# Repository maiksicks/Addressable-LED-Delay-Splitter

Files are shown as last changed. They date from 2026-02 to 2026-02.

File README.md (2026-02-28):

# Addressable LED Delay Splitter (WS2812B / SK6812)

This project implements a "delay splitter" for addressable LED strips (WS2812B / SK6812) using an [ATtiny406](https://www.microchip.com/en-us/product/attiny406) microcontroller.
The device should work for all 800 kHz LED strips that only use one data line.

> Inspired by [WS2812B Delay Splitter](https://hackaday.io/project/8181-ws2812b-delay-splitter) that uses a [CMIC](https://en.wikipedia.org/wiki/Configurable_mixed-signal_IC) for this task.

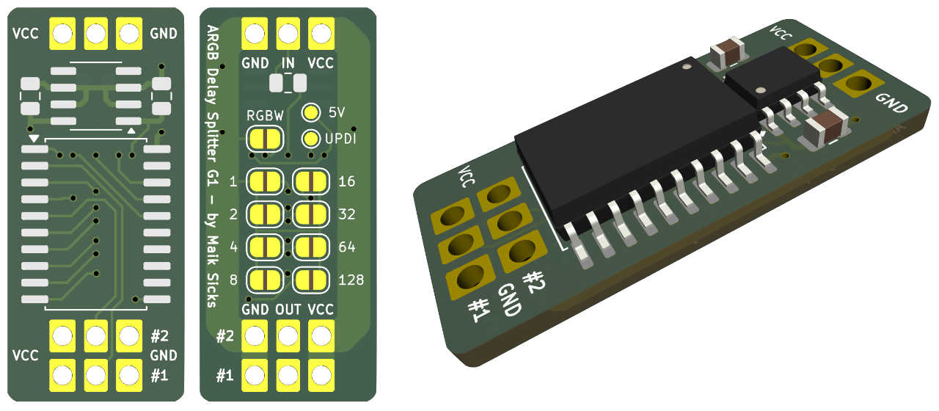
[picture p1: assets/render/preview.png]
Preview of the delay splitter


> [!NOTE]
> More images are available in the [Gallery](./docs/Gallery.md). Including a short demo video showing the device in action.

## Description

The splitter takes a single LED data stream as input and provides two outputs:

- **Primary output**: This channel outputs the first N pixels of the input stream, where N is the configured pixel number.

- **Secondary output**: This channel outputs the remaining pixels of the input stream after the first N pixels.

### Basic use-case

- `pixel delay = 3`
    ```
                                 +- (1) - (2) - (3)
    [Controller] --- [Splitter] -+
                                 +- (4) - (5) - (6)
    ```

- `pixel delay = 3` and `primary passthrough = on`
    ```
                                 +- (1) - (2) - (3) - (4) - (5) - (6)
    [Controller] --- [Splitter] -+
                                 +- (4) - (5) - (6)
    ```

- Chaining
    ```
                                 +- (1) - (2) - (3)
    [Controller] --- [Splitter] -+
                                 +- [Splitter] ...
    ```
    ```
    [Controller] --- (1) - (2) - (3) --- [Splitter] ...
    ```

### How it works

Due to the high frequency of the WS2812B protocol (800kHz, 1.25µs per bit), the splitter uses many hardware features of the ATtiny406 to achieve the required timing:

- **Event System**
  Distribute the different signals (data input and control pin) to the various peripherals w(mostly) without CPU intervention.

- **CCL (Configurable Custom Logic)**
  Look-up tables (LUTs) are used to asynchronously route the input data stream to the outputs.

  - `Output_1 = Input_1 AND NOT Control_Pin`
  - `Output_2 = Input_1 AND Control_Pin`

- **TCA0 (Bit Counter)**
  Counts the number of bits / rising edges / events received via the event system. When the configured number of bits (delay) is reached, the control pin is switched to route the data to output 2.

- **TCB0 (Timeout Timer)**
  When the control pin is switched to output 2, this timer is started. If no rising edges are detected for a certain amount of time (indicating the reset condition of the WS2812B), the control pin is switched back to output 1.

## Configuration

The device can be configured via jumpers or by hardcoding values in `config.hpp`.

### Jumper configuration

There are 8 jumpers available to configure the pixel delay. The delay can be set from 0 to 255 pixels.

There is an additional jumper to change from RGB mode (24 bits per pixel) to RGBW mode (32 bits per pixel).

### Hardcoded configuration

The following parameters can be hardcoded in `config.hpp`:

- `PIXEL_DELAY` - Number of pixels to delay the output
- `RGBW_MODE` - Enable RGBW mode (32 bits per pixel instead of 24)
- `BITS_PER_PIXEL` - Number of bits per pixel (24 for RGB, 32 for RGBW)
- `SWAP_OUTPUTS` - Swap the primary and secondary outputs (output 1 and output 2)
- `PRIMARY_OUTPUT_PASSTHROUGH` - Enable passthrough of the primary output. When enabled, the primary output will not be turned off when the secondary output is active.
- `DISABLE_OUTPUT_1` and `DISABLE_OUTPUT_2` - Self-explanatory :)
- `LED_RESET_TIMEOUT` - Duration (in microseconds) to detect the reset condition of the WS2812B. The default is 50µs, which is a safe value for up to ~800kHz data rates.

Special parameters:

- `FORCE_SHORTED_CONTROL_PIN` - Forces the _shorted configuration pin mode_ to be enabled. This mode will be automatically enabled if jumper "128" is used. The control signal will then be inverted internally instead of setting the pin HIGH and LOW. 
  _Background: This mode had to be introduced because the hardware design of the splitter (revision 1) already had all Port B pins used for the configuration jumpers. The Event System only supports Port B pins as event generators on `ASYNCCH1`._

### Operation voltage

The device contains an onboard voltage regulator that can accept input voltages up to 30V (absolute maximum rating). Therefore, the recommend input voltages are 12V and 24V.

It is also possible to power the device with 5V. However, in this case, the voltage regulator will not be able to provide a stable 5V output for the ATtiny406. It may be a good idea to remove the voltage regulator and connect the 5V pin directly to the VCC pin.

### Flashing

The project can be built and flashed using [PlatformIO](https://platformio.org/).

For flashing, an UPDI programmer is required. 
You can also build a simple UPDI programmer using an Arduino Uno/Nano with ATmega328P:

1. Download the [jtag2updi repository](https://github.com/ElTangas/jtag2updi).
2. Rename the `source` folder to `jtag2updi` (otherwise Arduino IDE will not open it).
3. Open the `jtag2updi.ino` file using the Arduino IDE.
4. Connect the Arduino, select the correct board and port in the Arduino IDE, and upload the sketch.

After this, you can connect pin 6 of the Arduino to the UPDI pin of the ATtiny406, and use PlatformIO to flash the splitter firmware.

## Limitations

There is a maximum amount of leds that can be connected to a single data line. This limit is determined by the data rate of the LEDs. The formula to calculate the maximum number of LEDs is:

`N = ( (1 / f) - T_reset ) / ( B / R )`

Where:
- `N` = maximum number of LEDs
- `f` = frames per second (e.g. 60Hz)
- `T_reset` = reset time of the LEDs (e.g. 50µs)
- `B` = bits per pixel (e.g. 24 for RGB, 32 for RGBW)
- `R` = data rate in bits per second (e.g. 800,000 bps)

Example:
- With 60 Hz and RGB LEDs: up to 553 LEDs
- With 60 Hz and RGBW LEDs: up to 415 LEDs

- With 30 Hz and RGB LEDs: up to 1109 LEDs
- With 30 Hz and RGBW LEDs: up to 832 LEDs

## Ordering PCBs

Read the [README](./kicad/Addressable_LED_Delay_Splitter/README.md) in the `kicad` folder for details on the PCB design and order.

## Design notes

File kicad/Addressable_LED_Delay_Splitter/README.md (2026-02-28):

# Addressable LED Delay Splitter (PCB)

This folder contains the [KiCad](https://kicad.org/) project for the Addressable LED Delay Splitter PCB.

## Production files

Production files can be found in the `jlcpcb/production_files` folder.
These files were generated by the [KiCAD JLCPCB tools plugin](https://github.com/bouni/kicad-jlcpcb-tools).

It should be possible to upload the GERBER archive to other PCB manufacturers as well, but this has not been tested.

The BOM and CPL files are in the format required by [JLCPCB](https://jlcpcb.com/).

It may be required to check and adjust the part numbers before ordering, because parts are from time to time replaced or go out of stock.

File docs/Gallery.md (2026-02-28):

# Addressable LED Delay Splitter - Gallery

## Demo video

https://github.com/user-attachments/assets/cb7658ee-294e-4ca6-bfc9-5e69e2aed46c

In this example video, the device is configured to send the first 10 pixels to the primary output and the remaining pixels to the secondary output.
Additionally, the RGBW jumper is set.

The device visible in the bottom left corner is my ESP32-S3 based ARGB controller. It has two ARGB outputs, 4 IOs, Power measurment, Ethernet and some other features. It is not related to the delay splitter, but I thought it would be nice to show it as well. The controller is designed to be used as low-latency UDP to ARGB bridge and it runs ESPHome firmware with custom components. It can be also flashed with WLED firmware, but the support for the W5500 ethernet module is tricky.
(Separate project, will be published soon ...)

Direct links: [Video](../assets/media/demo.mp4), [Image](../assets/media/demo_setup.jpeg)

## Images

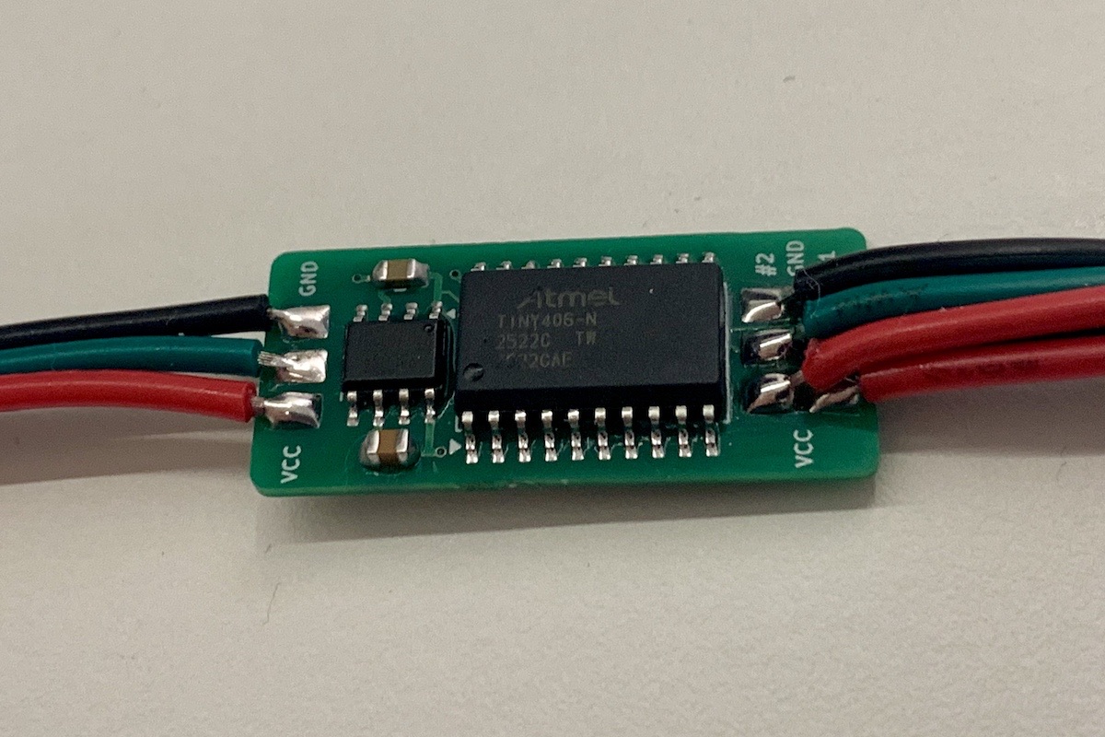
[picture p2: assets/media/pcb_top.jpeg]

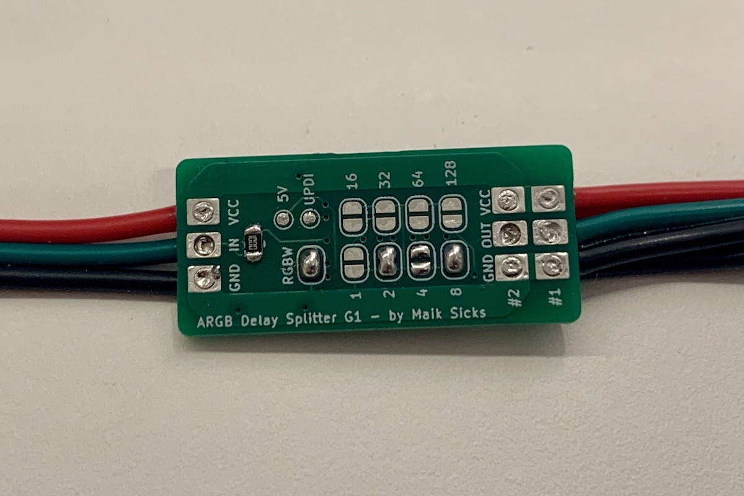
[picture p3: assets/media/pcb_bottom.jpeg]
Bottom view of the delay splitter


<br>
Note: I've hand soldered the PCB because I don't need more than a few devices. It is possible to get assembled PCBs. The size however requires the PCBs do be panelized, which increases the amount of final PCBs and parts a lot and thus the cost.

## Rendered images

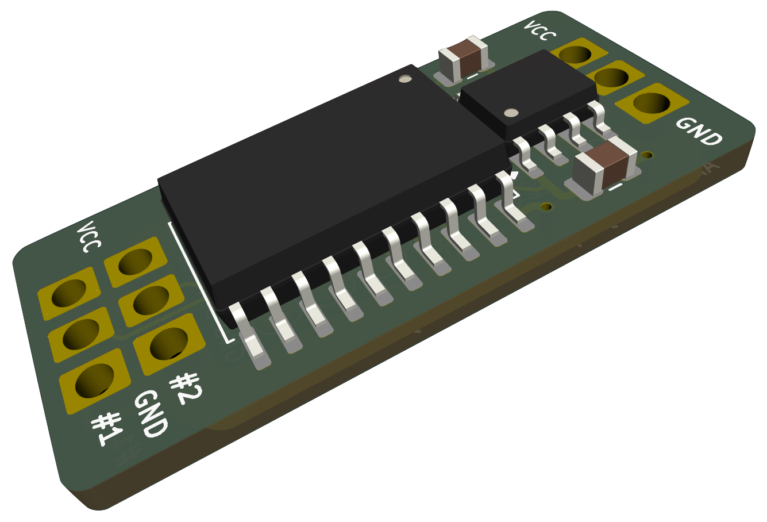
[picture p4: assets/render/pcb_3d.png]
3D view of the delay splitter

<br>
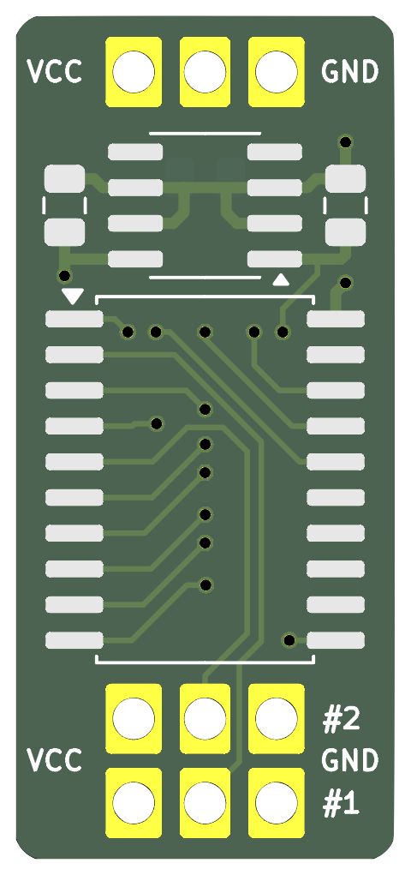
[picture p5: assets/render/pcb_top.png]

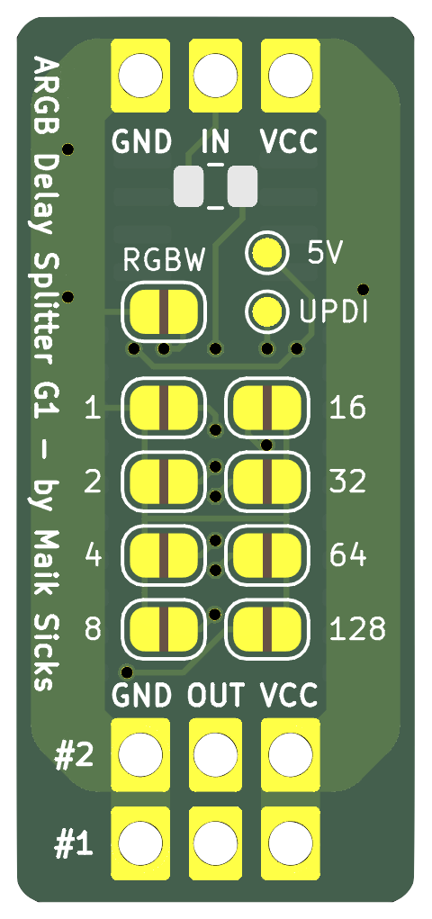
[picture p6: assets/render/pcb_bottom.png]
Bottom view of the delay splitter


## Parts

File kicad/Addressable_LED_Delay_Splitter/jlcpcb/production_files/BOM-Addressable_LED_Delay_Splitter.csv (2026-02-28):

Comment | Designator | Footprint | LCSC | Quantity
ATtiny406-S | U3 | SOIC-20W_7.5x12.8mm_P1.27mm | C1338099 | 1
100n | C2 | C_0805_2012Metric | C13967 | 1
120 | R1 | R_0805_2012Metric | C17437 | 1
330n | C1 | C_0805_2012Metric | C49678 | 1
L78L05_SO8 | U2 | SOIC-8_3.9x4.9mm_P1.27mm | C7543 | 1

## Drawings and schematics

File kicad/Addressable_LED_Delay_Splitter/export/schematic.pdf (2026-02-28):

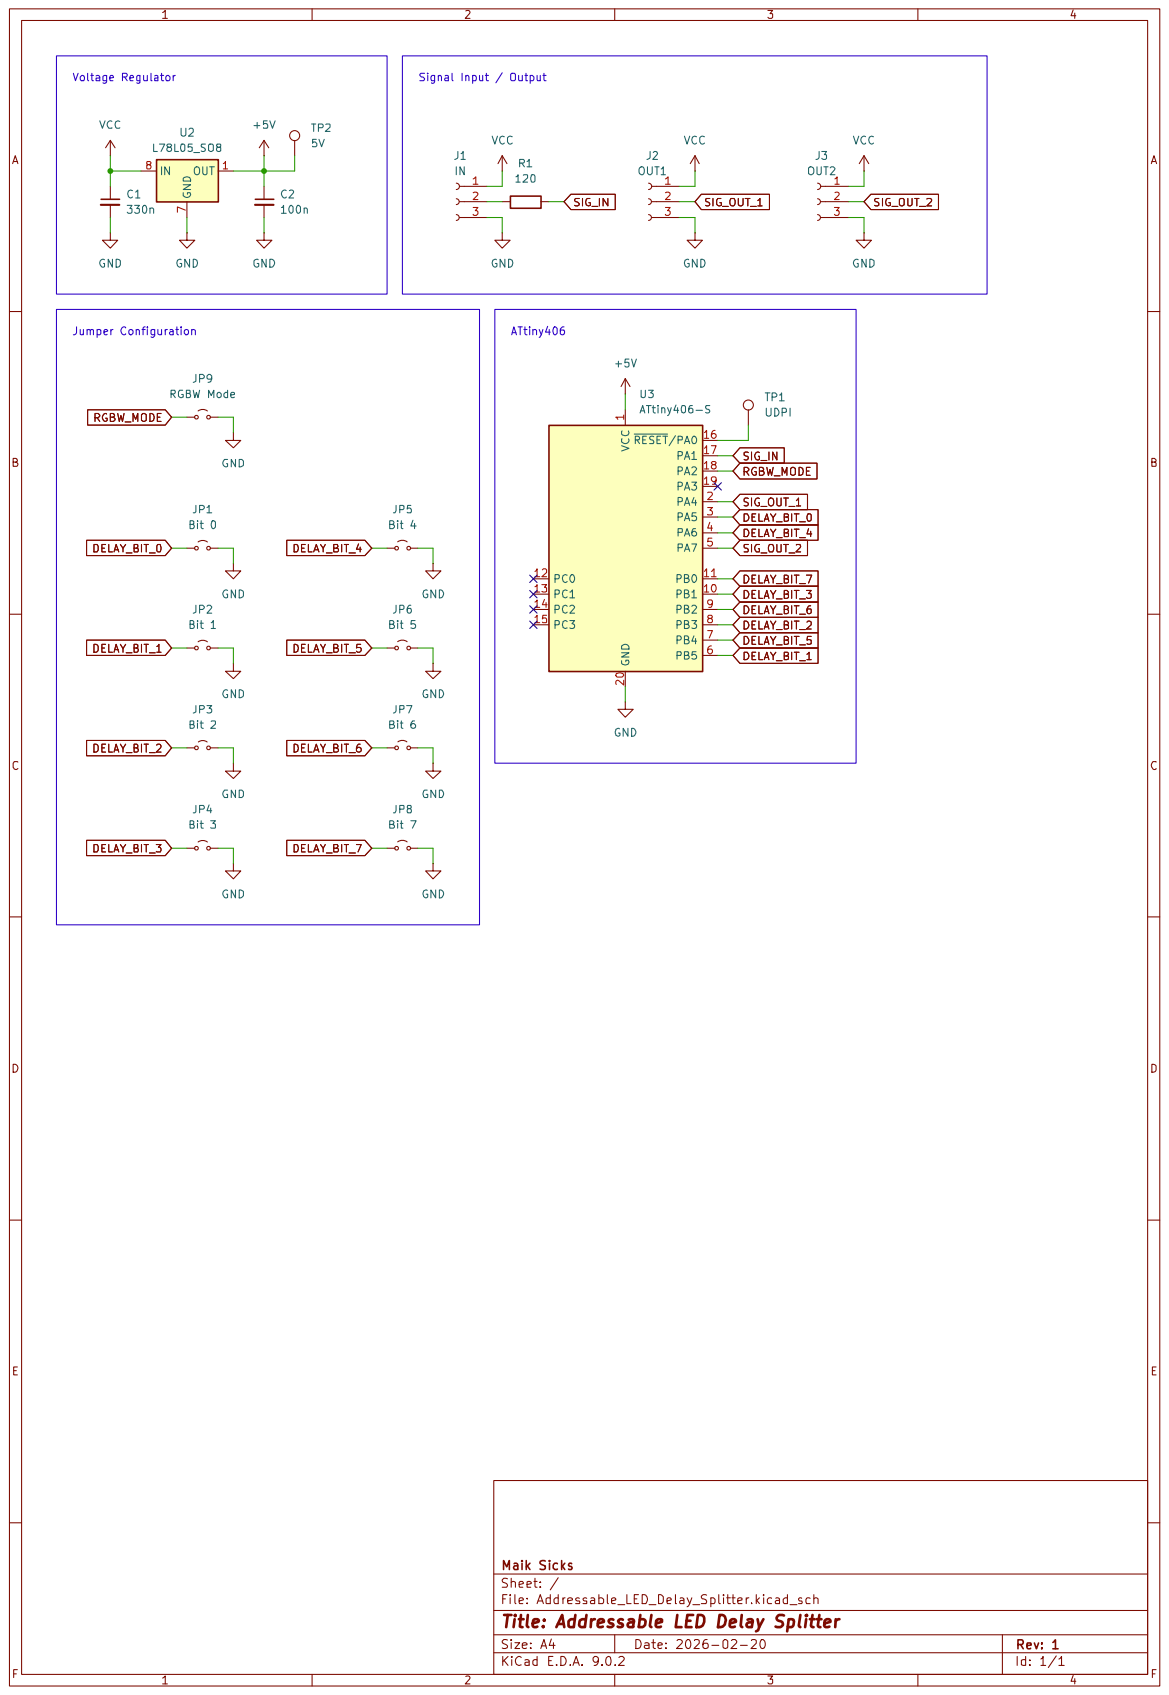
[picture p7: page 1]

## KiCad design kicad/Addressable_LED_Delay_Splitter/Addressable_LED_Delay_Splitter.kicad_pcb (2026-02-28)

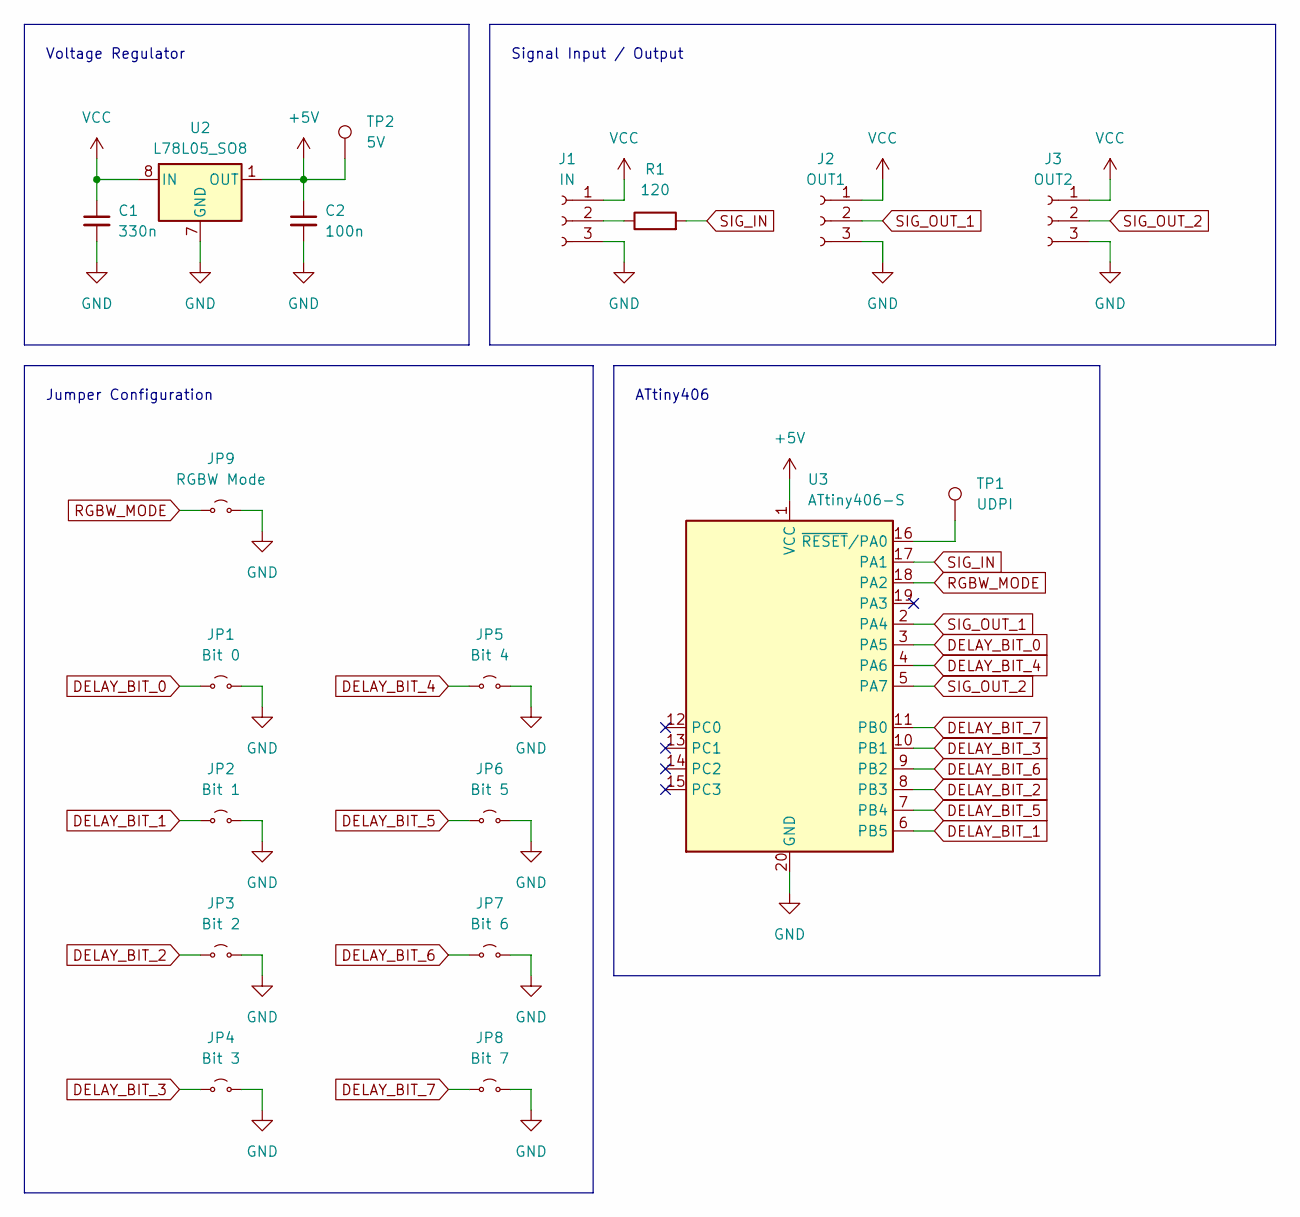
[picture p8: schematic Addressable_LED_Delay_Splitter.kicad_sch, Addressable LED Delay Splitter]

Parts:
C1: 330n; C_0805_2012Metric; LCSC C49678
C2: 100n; C_0805_2012Metric; LCSC C13967
J1: IN; ARGB_Solder_Header
J2: OUT1; ARGB_Solder_Header
J3: OUT2; ARGB_Solder_Header
JP1: Bit 0; SolderJumper-2_P1.3mm_Open_RoundedPad1.0x1.5mm
JP2: Bit 1; SolderJumper-2_P1.3mm_Open_RoundedPad1.0x1.5mm
JP3: Bit 2; SolderJumper-2_P1.3mm_Open_RoundedPad1.0x1.5mm
JP4: Bit 3; SolderJumper-2_P1.3mm_Open_RoundedPad1.0x1.5mm
JP5: Bit 4; SolderJumper-2_P1.3mm_Open_RoundedPad1.0x1.5mm
JP6: Bit 5; SolderJumper-2_P1.3mm_Open_RoundedPad1.0x1.5mm
JP7: Bit 6; SolderJumper-2_P1.3mm_Open_RoundedPad1.0x1.5mm
JP8: Bit 7; SolderJumper-2_P1.3mm_Open_RoundedPad1.0x1.5mm
JP9: RGBW Mode; SolderJumper-2_P1.3mm_Open_RoundedPad1.0x1.5mm
R1: 120; R_0805_2012Metric; LCSC C17437
TP1: UDPI; TestPoint_Pad_D1.0mm
TP2: 5V; TestPoint_Pad_D1.0mm
U2: L78L05_SO8; SOIC-8_3.9x4.9mm_P1.27mm; LCSC C7543
U3: ATtiny406-S; SOIC-20W_7.5x12.8mm_P1.27mm; LCSC C1338099

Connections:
+5V: C2.1, TP2.1, U2.1 (OUT), U3.1 (VCC)
DELAY_BIT_0: JP1.1 (A), U3.3 (PA5)
DELAY_BIT_1: JP2.1 (A), U3.6 (PB5)
DELAY_BIT_2: JP3.1 (A), U3.8 (PB3)
DELAY_BIT_3: JP4.1 (A), U3.10 (PB1)
DELAY_BIT_4: JP5.1 (A), U3.4 (PA6)
DELAY_BIT_5: JP6.1 (A), U3.7 (PB4)
DELAY_BIT_6: JP7.1 (A), U3.9 (PB2)
DELAY_BIT_7: JP8.1 (A), U3.11 (PB0)
GND: C1.2, C2.2, J1.3, J2.3, J3.3, JP1.2 (B), JP2.2 (B), JP3.2 (B), JP4.2 (B), JP5.2 (B), JP6.2 (B), JP7.2 (B), JP8.2 (B), JP9.2 (B), U2.2 (GND), U2.3 (GND), U2.6 (GND), U2.7 (GND), U3.20 (GND)
unnamed: J1.2, R1.1
unnamed: TP1.1, U3.16 (~RESET/PA0)
RGBW_MODE: JP9.1 (A), U3.18 (PA2)
SIG_IN: R1.2, U3.17 (PA1)
SIG_OUT_1: J2.2, U3.2 (PA4)
SIG_OUT_2: J3.2, U3.5 (PA7)
VCC: C1.1, J1.1, J2.1, J3.1, U2.8 (IN)

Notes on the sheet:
ATtiny406
Signal Input / Output
Voltage Regulator
Jumper Configuration

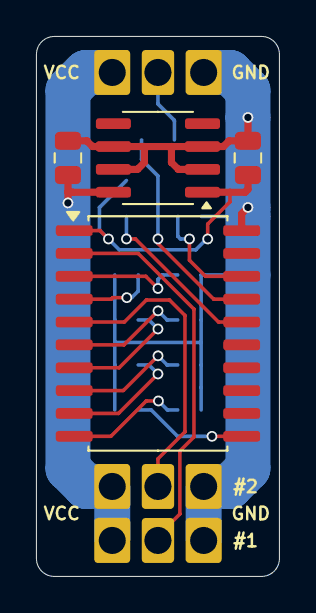
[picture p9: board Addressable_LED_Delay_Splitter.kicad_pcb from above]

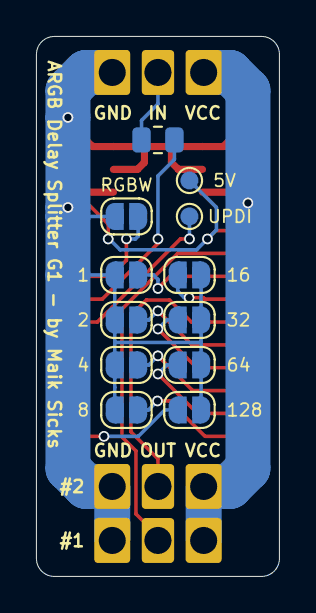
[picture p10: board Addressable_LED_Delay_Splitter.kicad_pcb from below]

Board: 2 copper layers, 13.5 x 30.0 mm, 19 parts (12 on the bottom side), 17 nets.

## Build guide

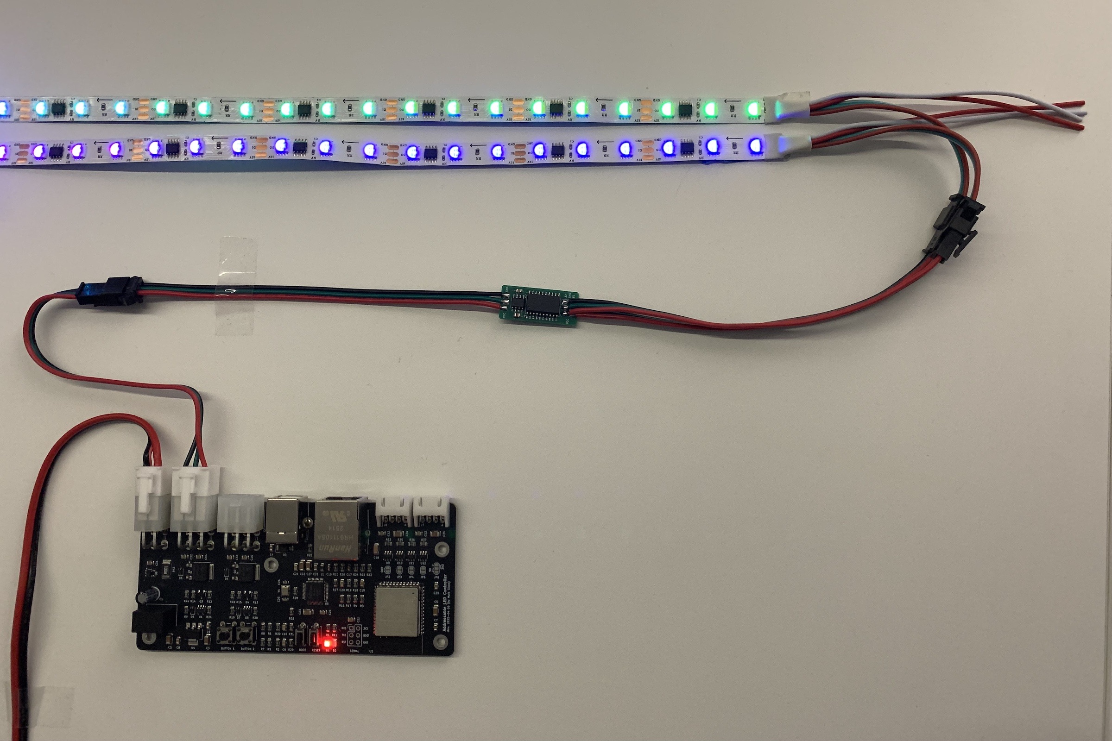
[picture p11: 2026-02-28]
assets/media/demo_setup.jpeg

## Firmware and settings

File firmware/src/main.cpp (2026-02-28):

/**
 * WS2812B Signal Splitter for ATTiny406
 *
 * Splits an incoming WS2812B signal into two outputs based on pixel count.
 * - First N pixels go to Output 1 (PA4 / LUT0-OUT)
 * - Remaining pixels go to Output 2 (PA7 / LUT1-OUT)
 */


#include <avr/io.h>
#include <avr/interrupt.h>
#include <util/delay.h>

#include "config.hpp"

// =============================================================================
// Global Variables
// =============================================================================

volatile uint16_t targetBits = 0;
volatile bool controlPinShorted = false;


// =============================================================================
// Output Control Functions
// =============================================================================

static inline void enableOutput1() {
  if (controlPinShorted) {
    // Disable invert
    PORTB.PIN0CTRL &= ~PORT_INVEN_bm;
  } else {
    // Set control pin LOW
    PORTB.OUTCLR = PIN0_bm;
  }
}

static inline void enableOutput2() {
  if (controlPinShorted) {
    // Enable invert
    PORTB.PIN0CTRL |= PORT_INVEN_bm;
  } else {
    // Set control pin HIGH
    PORTB.OUTSET = PIN0_bm;
  }
}


// =============================================================================
// Setup Functions
// =============================================================================

/**
 * Configure the main system clock
 */
void setupClock() {
  // No prescaler => 20 MHz
  _PROTECTED_WRITE(CLKCTRL.MCLKCTRLB, 0);
}

/**
 * Disable unused peripherals to save power
 */
void disableUnusedPeripherals() {
  // Disable ADC
  ADC0.CTRLA = 0;

  // Disable AC
  AC0.CTRLA = 0;

  // Disable VREF
  VREF.CTRLA = 0;
  VREF.CTRLB = 0;

  // Disable USART
  USART0.CTRLB = 0;

  // Disable TWI/I2C
  TWI0.MCTRLA = 0;
  TWI0.SCTRLA = 0;

  // Disable SPI
  SPI0.CTRLA = 0;
}

/**
 * Initialize configuration
 *
 * Reads configuration from GPIO pins if READ_CONFIG_FROM_JUMPERS is defined,
 * otherwise uses hardcoded values.
 *
 * Also detects if PB0 is shorted to ground and adjusts control logic accordingly.
 *
 * Delay pixel count (8-bit value):
 *   PA5: Bit 0 (LSB)
 *   PB5: Bit 1
 *   PB3: Bit 2
 *   PB1: Bit 3
 *   PA6: Bit 4
 *   PB4: Bit 5
 *   PB2: Bit 6
 *   PB0: Bit 7 (MSB)
 *
 * RGBW mode:
 *   PA2: RGBW enable (1 = 32 bits/pixel, 0 = 24 bits/pixel)
 *
 * Pins are read with pull-ups enabled:
 *   - Grounded pin = 1 (jumper installed)
 *   - Floating pin = 0 (no jumper)
 *
 * Pull-ups are disabled after reading.
 */
void init() {

  uint16_t pixel_delay = 0;
  uint8_t bits_per_pixel = 0;

  #ifdef READ_CONFIG_FROM_JUMPERS

    // Configure pins as inputs with pull-ups enabled
    PORTA.DIRCLR = PIN2_bm | PIN5_bm | PIN6_bm;
    PORTA.PIN2CTRL = PORT_PULLUPEN_bm;
    PORTA.PIN5CTRL = PORT_PULLUPEN_bm;
    PORTA.PIN6CTRL = PORT_PULLUPEN_bm;

    PORTB.DIRCLR = PIN0_bm | PIN1_bm | PIN2_bm | PIN3_bm | PIN4_bm | PIN5_bm;
    PORTB.PIN0CTRL = PORT_PULLUPEN_bm;
    PORTB.PIN1CTRL = PORT_PULLUPEN_bm;
    PORTB.PIN2CTRL = PORT_PULLUPEN_bm;
    PORTB.PIN3CTRL = PORT_PULLUPEN_bm;
    PORTB.PIN4CTRL = PORT_PULLUPEN_bm;
    PORTB.PIN5CTRL = PORT_PULLUPEN_bm;

    // Small delay to let pull-ups stabilize
    _delay_us(100);

    // Read RGBW mode from PA2
    bool rgbw_mode = !(PORTA.IN & PIN2_bm);

    if (rgbw_mode) {
      bits_per_pixel = BITS_PER_PIXEL_RGBW;
    } else {
      bits_per_pixel = BITS_PER_PIXEL_RGB;
    }

    // Read pin states and build the delay pixel value
    // With pull-ups: grounded = 1, floating = 0
    if (!(PORTA.IN & PIN5_bm)) pixel_delay |= (1 << 0);  // Bit 0
    if (!(PORTB.IN & PIN5_bm)) pixel_delay |= (1 << 1);  // Bit 1
    if (!(PORTB.IN & PIN3_bm)) pixel_delay |= (1 << 2);  // Bit 2
    if (!(PORTB.IN & PIN1_bm)) pixel_delay |= (1 << 3);  // Bit 3
    if (!(PORTA.IN & PIN6_bm)) pixel_delay |= (1 << 4);  // Bit 4
    if (!(PORTB.IN & PIN4_bm)) pixel_delay |= (1 << 5);  // Bit 5
    if (!(PORTB.IN & PIN2_bm)) pixel_delay |= (1 << 6);  // Bit 6
    if (!(PORTB.IN & PIN0_bm)) pixel_delay |= (1 << 7);  // Bit 7

    #ifndef FORCE_SHORTED_CONTROL_PIN
      // Check if PB0 is shorted to ground
      if (pixel_delay & (1 << 7)) {
        controlPinShorted = true;
      }
    #endif

    // Disable pull-ups after reading
    PORTA.PIN2CTRL = 0;
    PORTA.PIN5CTRL = 0;
    PORTA.PIN6CTRL = 0;
    PORTB.PIN0CTRL = 0;
    PORTB.PIN1CTRL = 0;
    PORTB.PIN2CTRL = 0;
    PORTB.PIN3CTRL = 0;
    PORTB.PIN4CTRL = 0;
    PORTB.PIN5CTRL = 0;

  #else
    // Use hardcoded configuration values

    #ifndef FORCE_SHORTED_CONTROL_PIN
      // Check if PB0 is shorted to ground by configuring it as input with pull-up and reading its state
      PORTB.DIRCLR = PIN0_bm;
      PORTB.PIN0CTRL = PORT_PULLUPEN_bm;

      _delay_us(100);

      if (!(PORTB.IN & PIN0_bm)) {
        // Pin is shorted to ground => use pin-invert as control signal
        controlPinShorted = true;
      }

      PORTB.PIN0CTRL = 0;
    #endif

    bits_per_pixel = BITS_PER_PIXEL;
    pixel_delay = PIXEL_DELAY;
  #endif

  targetBits = pixel_delay * bits_per_pixel;

  #ifdef FORCE_SHORTED_CONTROL_PIN
    controlPinShorted = true;
  #endif
}

/**
 * Configure GPIO pins
 */
void setupPins() {
  // PA1: Input (WS2812B data input)
  PORTA.DIRCLR = PIN1_bm;

  // PA4 and PA7 direction is controlled by CCL when OUTEN is enabled
  // But we set them as outputs for clarity
  PORTA.DIRSET = PIN4_bm | PIN7_bm;

  // PB0: Control pin for output switching
  if (controlPinShorted) {
    // Use PB0 as input. Toggle invert flag to trigger events.
    PORTB.DIRCLR = PIN0_bm;
  } else {
    // Use PB0 as output. Toggle output to trigger events.
    PORTB.DIRSET = PIN0_bm;
    PORTB.OUTSET = PIN0_bm;
  }
}

/**
 * Configure the Event System
 *
 * Routes PA1 signal to:
 * - Both LUTs via Async Event Channel 0 (for signal buffering)
 * - TCA0 via Sync Event Channel 0 (for hardware bit counting)
 *
 * Routes PB0 signal to:
 * - Both LUTs via Async Event Channel 1 (for output control)
 */
void setupEventSystem() {
  // Async Channel 0: PA1 (data signal) for both LUTs
  EVSYS.ASYNCCH0 = EVSYS_ASYNCCH0_PORTA_PIN1_gc;

  // Async Channel 1: PB0 (control signal) for both LUTs
  EVSYS.ASYNCCH1 = EVSYS_ASYNCCH1_PORTB_PIN0_gc;

  // Route Async Channel 0 to both LUT0 and LUT1 Event 0 inputs
  // ASYNCUSER2 = LUT0 Event 0 input
  // ASYNCUSER3 = LUT1 Event 0 input
  EVSYS.ASYNCUSER2 = EVSYS_ASYNCUSER2_ASYNCCH0_gc;  // LUT0 E0 <- CH0 (data)
  EVSYS.ASYNCUSER3 = EVSYS_ASYNCUSER3_ASYNCCH0_gc;  // LUT1 E0 <- CH0 (data)

  // Route Async Channel 1 to both LUT0 and LUT1 Event 1 inputs
  // ASYNCUSER4 = LUT0 Event 1 input
  // ASYNCUSER5 = LUT1 Event 1 input
  EVSYS.ASYNCUSER4 = EVSYS_ASYNCUSER4_ASYNCCH1_gc;  // LUT0 E1 <- CH1 (control)
  EVSYS.ASYNCUSER5 = EVSYS_ASYNCUSER5_ASYNCCH1_gc;  // LUT1 E1 <- CH1 (control)

  // Sync Channel 0: PA1 (data signal) for TCA0
  EVSYS.SYNCCH0 = EVSYS_SYNCCH0_PORTA_PIN1_gc;

  // Route Sync Channel 0 to TCA0 for event counting
  // SYNCUSER0 = TCA0 Event input
  EVSYS.SYNCUSER0 = EVSYS_SYNCUSER0_SYNCCH0_gc;  // TCA0 <- SYNCCH0 (count rising edges)
}

/**
 * Configure the CCL (Configurable Custom Logic)
 *
 * Two LUTs are configured to control the outputs based on the data and control signals:
 * - LUT0 controls Output 1 (PA4)
 * - LUT1 controls Output 2 (PA7)
 *
 * Both LUTs use the same inputs:
 * - Input 0: Event 0 (data signal from PA1)
 * - Input 1: Event 1 (control signal from PB0)
 * - Input 2: Masked (forced to 0)
 */
void setupCCL() {
  // Disable CCL while configuring
  CCL.CTRLA = 0;

  // LUT0 Configuration (Output 1 - PA4)
  CCL.LUT0CTRLB = CCL_INSEL0_EVENT0_gc | CCL_INSEL1_EVENT1_gc;
  CCL.LUT0CTRLC = CCL_INSEL2_MASK_gc;

  // TRUTH0 table configuration
  CCL.TRUTH0 = TRUTH0_DATA;

  // Enable LUT0 with output to pin PA4
  CCL.LUT0CTRLA = CCL_OUTEN_bm | CCL_ENABLE_bm;

  // LUT1 Configuration (Output 2 - PA7)
  CCL.LUT1CTRLB = CCL_INSEL0_EVENT0_gc | CCL_INSEL1_EVENT1_gc;
  CCL.LUT1CTRLC = CCL_INSEL2_MASK_gc;

  // TRUTH1 table configuration
  CCL.TRUTH1 = TRUTH1_DATA;

  // Enable LUT1 with output to pin PA7
  CCL.LUT1CTRLA = CCL_OUTEN_bm | CCL_ENABLE_bm;

  // Enable the CCL peripheral
  CCL.CTRLA = CCL_ENABLE_bm;
}

/**
 * Configure TCA0 as event counter for bit counting
 *
 * Uses event input as clock source.
 * Generates overflow interrupt when count reaches targetBits, which triggers output switching.
 */
void setupEventCounter() {
  // Disable TCA0 while configuring
  TCA0.SINGLE.CTRLA = 0;

  // Configure for counting on event edges
  TCA0.SINGLE.CTRLB = TCA_SINGLE_WGMODE_NORMAL_gc;

  // Event control: count on positive edge of event, enable event counting
  TCA0.SINGLE.EVCTRL = TCA_SINGLE_EVACT_POSEDGE_gc | TCA_SINGLE_CNTEI_bm;

  // Set period to target bit count (interrupt fires when CNT reaches PER)
  TCA0.SINGLE.PER = targetBits - 2;

  // Enable overflow interrupt (fires when CNT reaches PER)
  TCA0.SINGLE.INTCTRL = TCA_SINGLE_OVF_bm;

  // Enable TCA0 - event system provides the clock
  TCA0.SINGLE.CTRLA = TCA_SINGLE_ENABLE_bm;
}

/**
 * Setup pin interrupts
 */
void setupPinInterrupts() {
  // Configure PA1 for rising edge interrupt,
  // used to restart timeout timer on data activity.
  PORTA.PIN1CTRL = PORT_ISC_RISING_gc;
}

/**
 * Configure TCB0 as timeout timer for reset detection
 */
void setupTimeoutTimer() {
  uint16_t timeoutCycles = CPU_CYCLES_FROM_MICROSECONDS(LED_RESET_TIMEOUT);

  // Disable while configuring
  TCB0.CTRLA = 0;

  // Periodic interrupt mode
  TCB0.CTRLB = TCB_CNTMODE_INT_gc;

  // Set compare value (generates interrupt when CNT reaches CCMP)
  TCB0.CCMP = timeoutCycles;

  // Enable capture/compare interrupt
  TCB0.INTCTRL = TCB_CAPT_bm;

  // Enable timer with CLK_PER, no prescaler
  TCB0.CTRLA = TCB_ENABLE_bm;
}


// =============================================================================
// Main Program
// =============================================================================

int main() {
  // Disable unused peripherals first for power saving
  disableUnusedPeripherals();

  // Initialize all peripherals
  setupClock();
  init();
  setupPins();
  setupEventSystem();
  setupCCL();

  if (targetBits < 2) {
    // Technical limitation: Counting less than 2 bits is not possible.
    // Therefor immediately switch to output 2 if targetBits is less than 2.
    enableOutput2();
  } else {
    setupEventCounter();
    setupPinInterrupts();
    setupTimeoutTimer();

    // Enable global interrupts
    sei();
  }

  while (1) {
    // Do nothing
  }
}


// =============================================================================
// Interrupt Service Routines
// =============================================================================

/**
 * Port A Pin Change Interrupt
 *
 * Triggered on rising edge of PA1 (WS2812B data input)
 * Resets the timeout timer to prevent false reset detection during active data
 */
ISR(PORTA_PORT_vect, ISR_NAKED) {
  // Clear the interrupt flag
  PORTA.INTFLAGS = PIN1_bm;

  // Reset timeout timer
  TCB0.CNT = 0;

  // Return from interrupt
  reti();
}

/**
 * TCA0 Overflow Interrupt
 *
 * Triggered when TCA0 event counter reaches targetBits
 * to switch the outputs after the configured pixel delay.
 */
ISR(TCA0_OVF_vect, ISR_NAKED) {
  // Clear the interrupt flag
  TCA0.SINGLE.INTFLAGS = TCA_SINGLE_OVF_bm;

  // Switch to Output 2
  enableOutput2();

  // Enable timeout timer to switch back to output 1
  TCB0.CTRLA = TCB_CLKSEL_CLKDIV1_gc | TCB_ENABLE_bm;

  // Return from interrupt
  reti();
}

/**
 * TCB0 Capture/Compare Interrupt
 *
 * Triggered when timeout has elapsed without data activity (no rising edges).
 * This indicates the WS2812B reset condition (line held LOW).
 */
ISR(TCB0_INT_vect, ISR_NAKED) {
  // Clear the interrupt flag
  TCB0.INTFLAGS = TCB_CAPT_bm;

  // Stop timeout timer
  TCB0.CTRLA = 0;

  // Verify the line is actually LOW (not just a long HIGH pulse)
  if (!(PORTA.IN & PIN1_bm)) {
    // Reset condition detected

    // Reset TCA0 event counter for new frame
    TCA0.SINGLE.CTRLA &= ~TCA_SINGLE_ENABLE_bm;
    TCA0.SINGLE.CNT = 0;
    TCA0.SINGLE.CTRLA |= TCA_SINGLE_ENABLE_bm;

    // Enable output 1
    enableOutput1();
  }

  // Return from interrupt
  reti();
}

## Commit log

2026-02-28 pcb: initial commit
    [Addressable_LED_Delay_Splitter.kicad_pcb, Addressable_LED_Delay_Splitter.kicad_sch, BOM-Addressable_LED_Delay_Splitter.csv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]
2026-02-28 firmware: fix macro name for jumper config
    [main.cpp]
2026-02-28 firmware: fix jumper bit
    [main.cpp]
2026-02-28 docs: clarify LED connection limits and provide calculation formula
2026-02-28 docs: add section about operation voltages
2026-03-19 firmware: add configuration sample when using UPDI friend
